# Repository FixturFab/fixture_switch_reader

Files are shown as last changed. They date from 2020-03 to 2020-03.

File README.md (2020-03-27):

# Fixture Switch Reader 

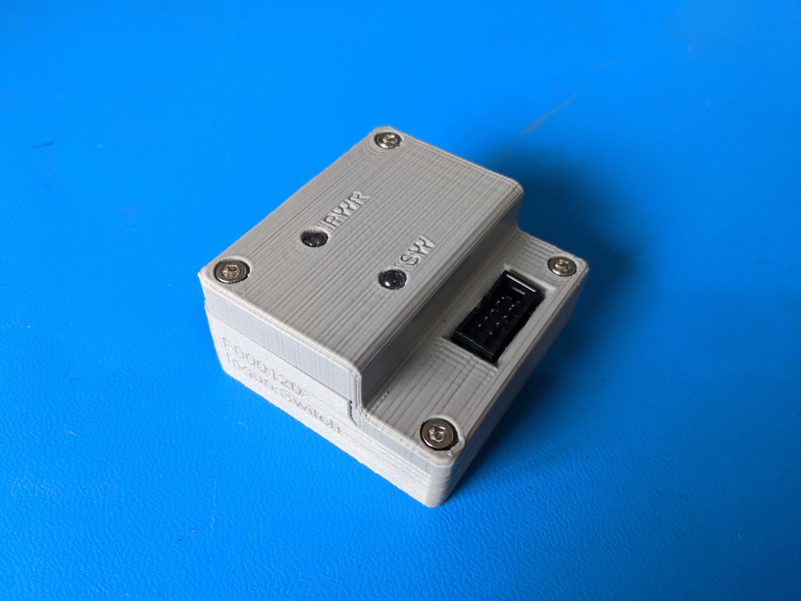
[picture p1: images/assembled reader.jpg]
Fixture Switch Reader


Project files for a USB Fixture Switch Reader using a SparkFun Pro Micro and a
Ingun FB-ABF-V-I-MA2xxx Inductive Switch. 

The Ingun FB-ABF-V-I-MA2xxx Inductive Switch is an inductive sensor which is
used to detect when a MA2xxx series manual test fixture is closed. 

FixturFab uses these switches to determine when a fixtures has been closed and
then automatically start a test run. The switch is powered by 12V, and also has 
a output of 12V when the fixture is closed. 

To interface this to a test system, an SparkFun Pro Micro is used to read the 
output of the sensor, and then relay that information to the test system over a
USB serial port. 

## Project Structure

The project is split into three main folders: 

- firmware
    - Arduino project and sketch for the SparkFun Pro Micro 
- hardware
    - Kicad schematic of the prototyped circuit 
    - Images of the perf board layout 
    - CAD files for the 3D printed enclosure 
- software 
    - Python module for communicating with the device
    
## Firmware 

Arduino 1.8.12 was used to build and program the sketch. 

The sketch reads the state of the switch input, sets the status LED, and then 
processes any available serial commands. The following serial commands are 
supported: 

- version 
    - Return device information and firmware version 
- read_switch
    - Return the current switch state 
    - 0: Fixture Open 
    - 1: Fixture Closed
    
The serial port is setup to use a BAUD rate of 115200. 
    
## Hardware 

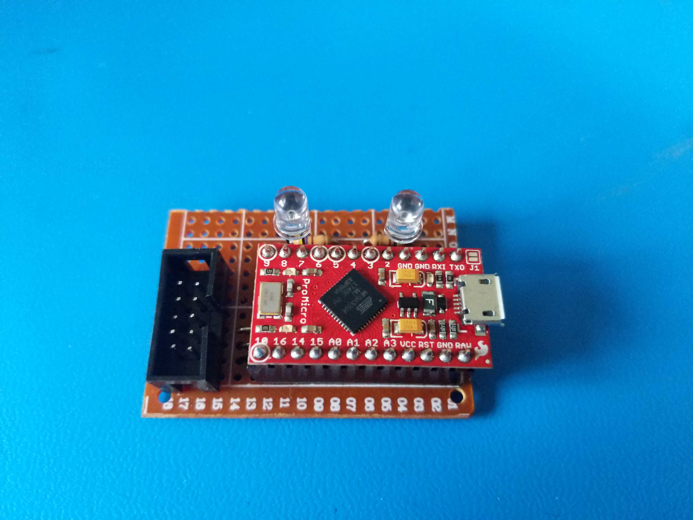
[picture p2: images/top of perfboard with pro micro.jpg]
Perfboard Prototype


A SparkFun Pro Micro was used to control this project. To build the circuit, 
perfboard and through-hole components were used. 

A Kicad schematic is available for the circuit layout. There are also pictures 
of the top and bottom of the perfboard. 

### Circuit Design and Layout 

We had a SparkFun Pro Micro (3.3V) available for this project. This device has
ATmega32u4 processor which is capable of USB communication, allowing for a USB 
serial port to be easily created. 

To interface the 12V output of the Inductive switch, a voltage divider is used. 

2 LEDs are also on the board, one connected to VCC of the processor, and the 
other is a status LED that is controlled by the processor. 

A Kicad schematic is included and shows how the circuit was prototyped, along 
with several images of the perf board layout. 

### Enclosure Design 

Fusion360 was used to design the enclosure. The enclosure consists of 2 pieces
that sandwich the protoyped device. The enclosure is held together using 
M3 heat-set inserts and fasteners. 

The STL and STEP files for the enclosure are included along with the Fusion360 
design file.  

## Software

Python 3+ is required for the provided software module. To get started, install
the required dependencies: 

```bash 
cd software/fixture_io
pip install -r requirements.text
```

To create a `FixtureSwitch` class, simple provide the serial port that the
device shows up as, for example: 

- Windows: "COM1"
- MAC: "cu.usbmodem146101"
- Linux: "/dev/ttyACM0"

```python
from fixture_io import FixtureSwitch
fixture_switch = FixtureSwitch("/dev/ttyACM0")

print(fixture_switch.get_info())
print(fixture_switch.read_switch())
```

The following API commands are available: 

- get_info()
    - Get the company, device, and firmware version from the device
- read_switch()
    - Read the switch state 
    - 0: Fixture Open 
    - 1: Fixture Closed

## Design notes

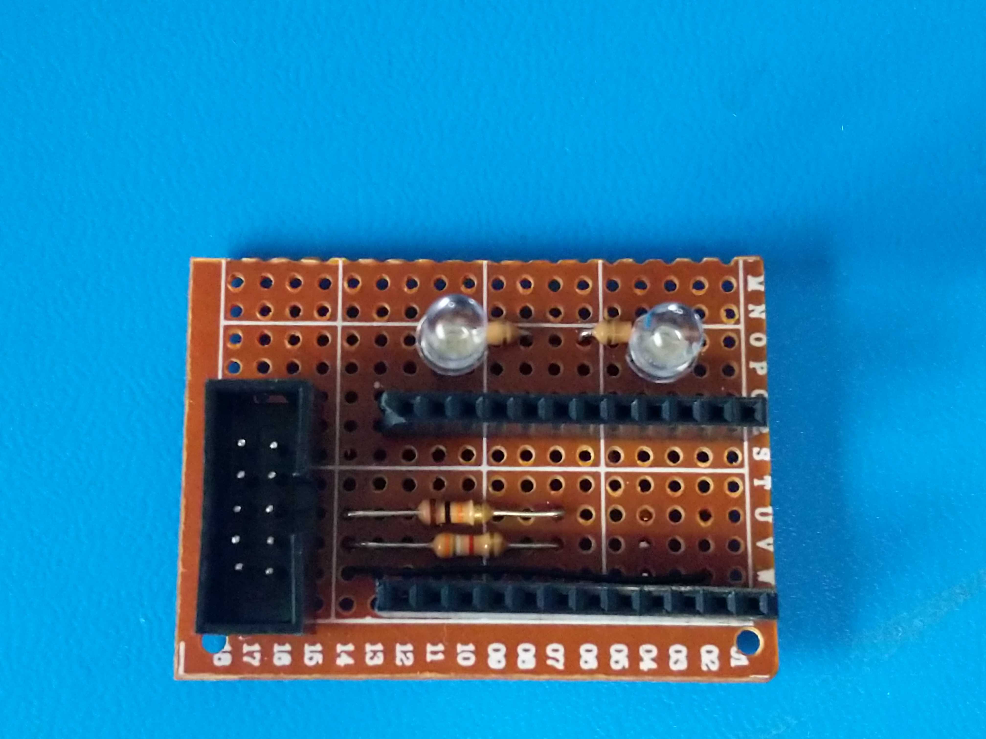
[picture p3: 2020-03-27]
hardware/fixture_switch_reader/top of perfboard.jpg

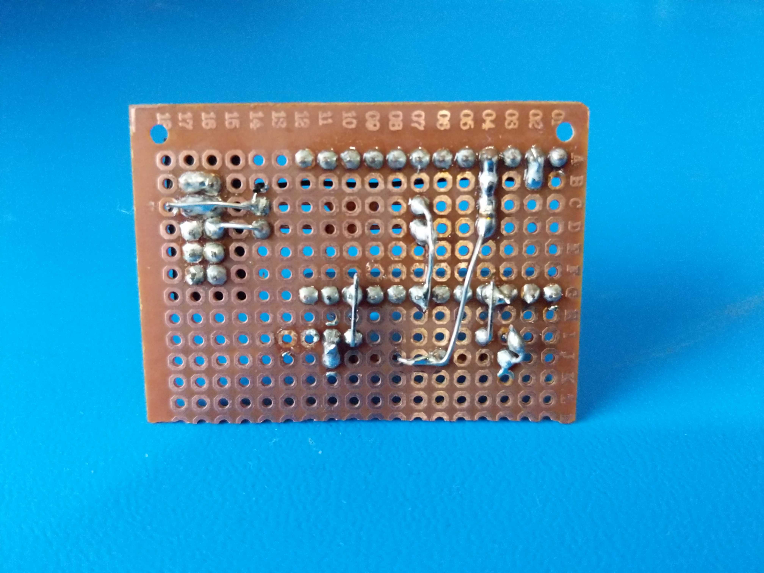
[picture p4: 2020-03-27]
hardware/fixture_switch_reader/back of perfboard.jpg

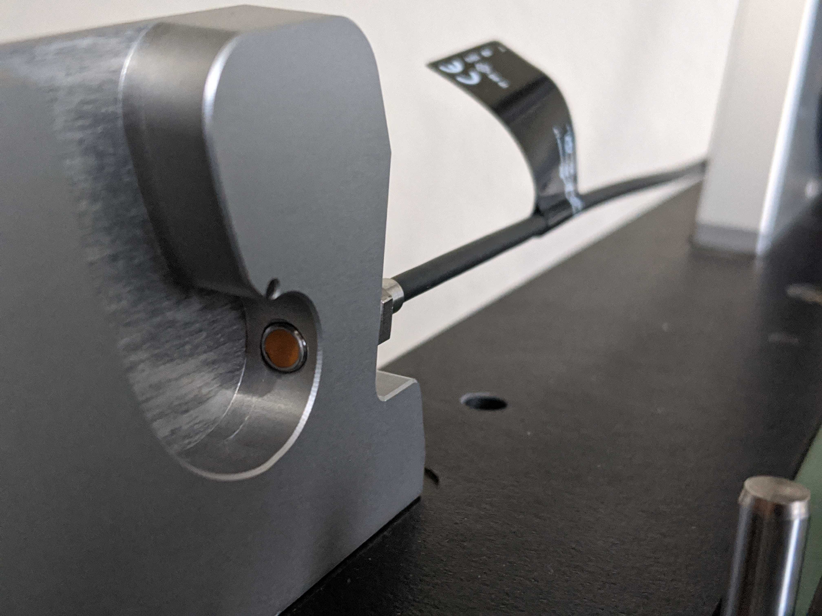
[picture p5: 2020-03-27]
images/ingun inductive sensor.jpg

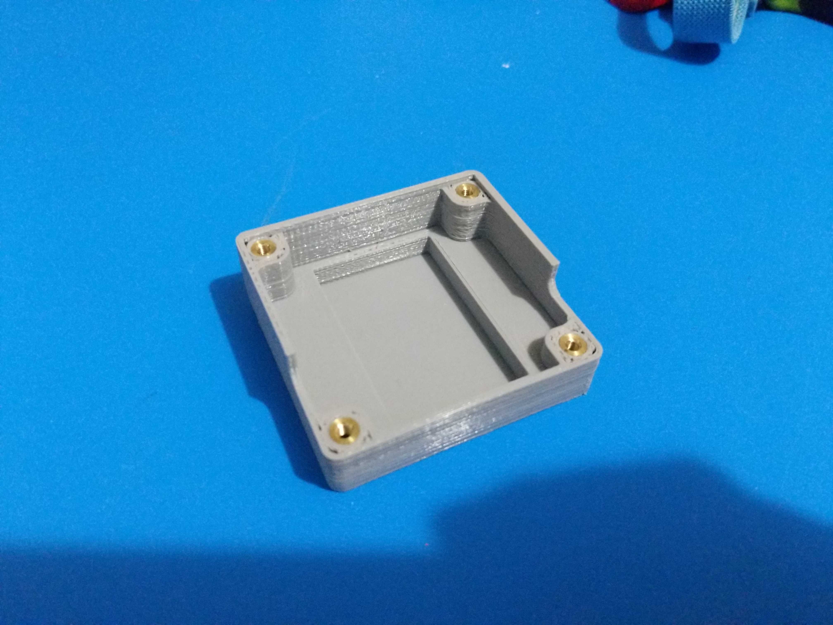
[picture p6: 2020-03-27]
images/bottom case with inserts.jpg

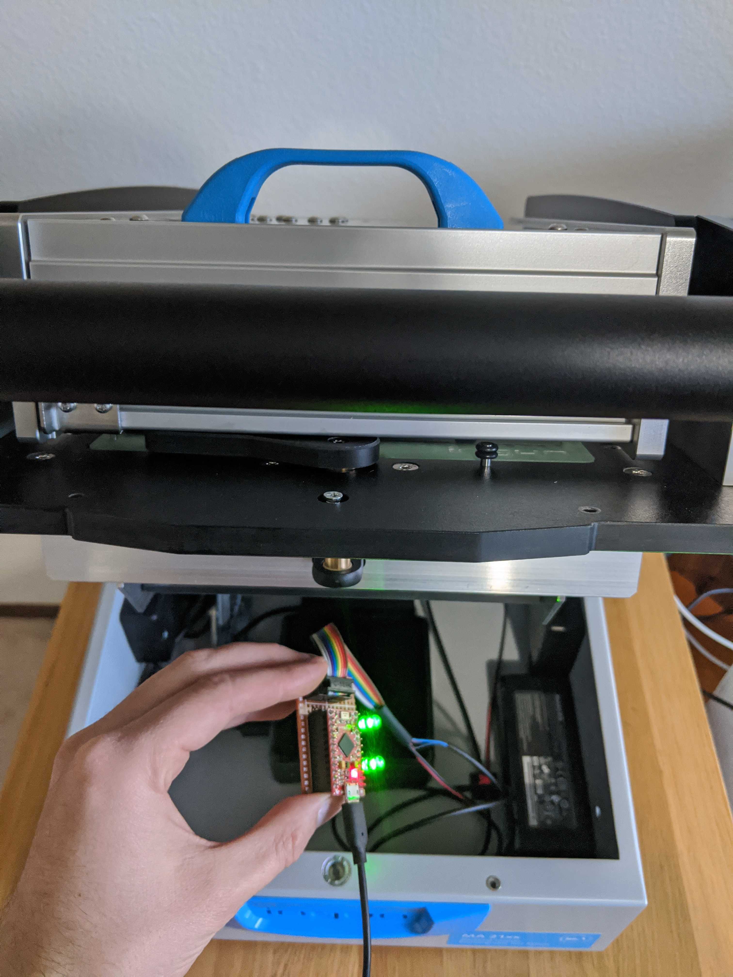
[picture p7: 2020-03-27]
images/fixture closed.jpg

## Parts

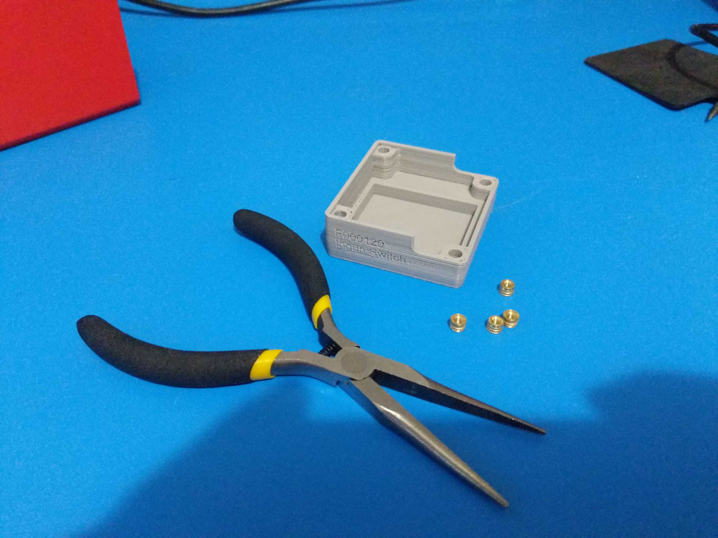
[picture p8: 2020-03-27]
images/bottom case insert parts.jpg

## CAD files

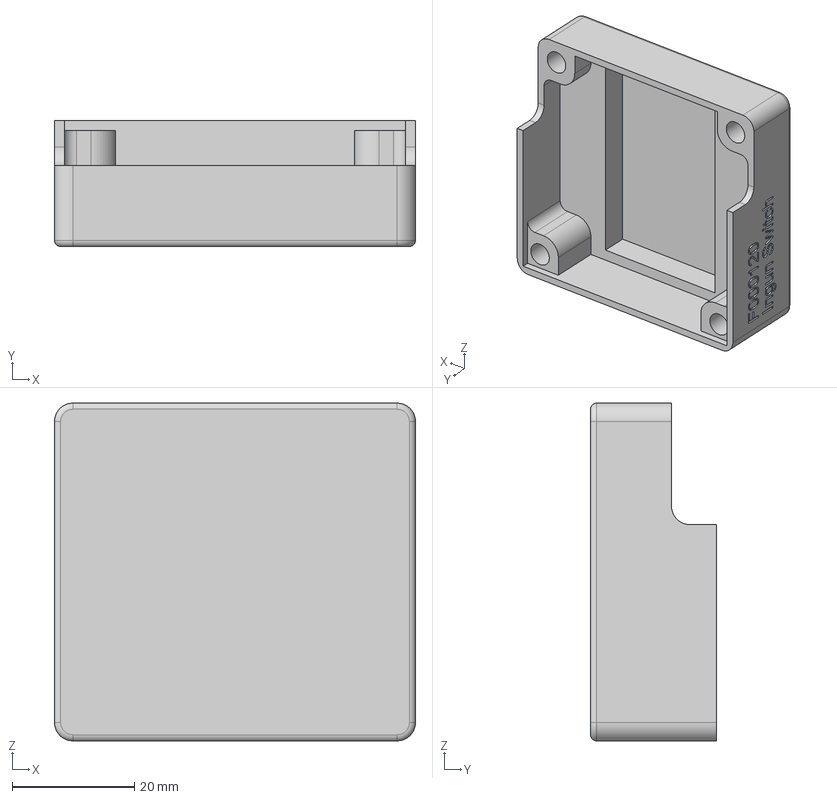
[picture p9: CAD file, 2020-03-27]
hardware/enclosure/F000118 - Case Bottom v25.step
59.0 x 20.6 x 55.2 mm

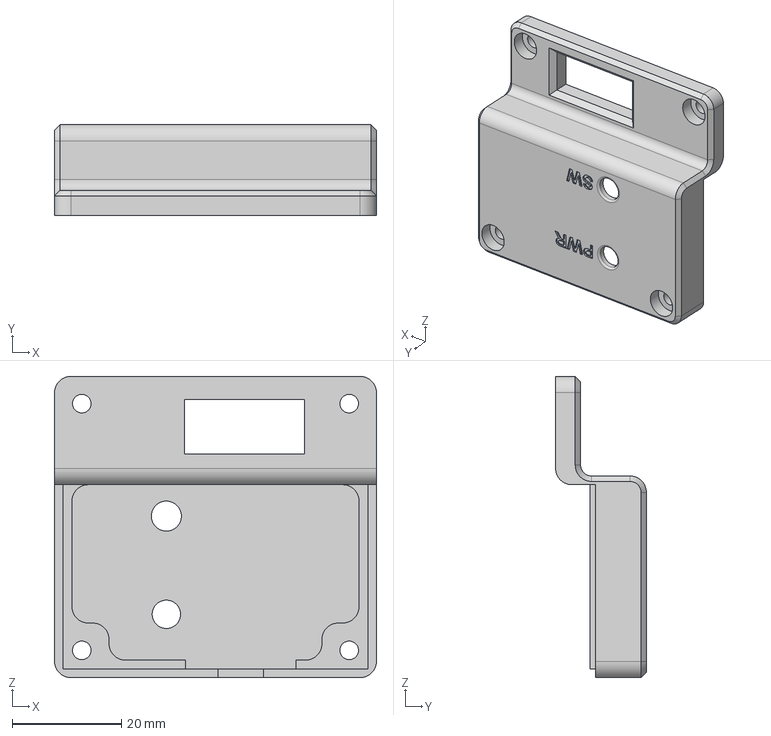
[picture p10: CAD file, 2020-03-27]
hardware/enclosure/F000119 - Case Top v43.step
59.0 x 16.6 x 55.2 mm

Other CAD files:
hardware/enclosure/F000118 - Case Bottom v25.stl
hardware/enclosure/F000119 - Case Top v43.stl
hardware/enclosure/F000120 - Protoype Ingun Switch Case Assembly v8.f3z

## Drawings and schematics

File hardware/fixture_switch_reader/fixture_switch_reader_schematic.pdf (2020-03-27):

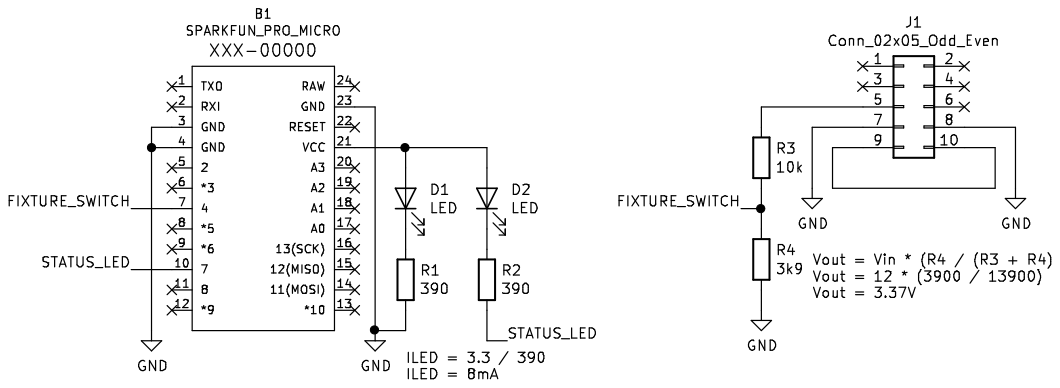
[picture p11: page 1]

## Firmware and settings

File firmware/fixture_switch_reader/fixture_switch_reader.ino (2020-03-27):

// Fixture Switch Reader
// SparkFun Micro Pro (3.3V) based USB IO Reader
//
// Connect using a serial terminal at 115200 BAUD
// Fixture Firmware Version
int FW_VER = 1;
// Pin Definitions
int STATUS_LED = 7;
int INGUN_PIN = 4;
// Global Variables
int sw_close = 0;
char buffer[256];
String command;
void setup()
{
  // Set switch pin as an input
  pinMode(INGUN_PIN, INPUT);
  // Set LED as an output
  pinMode(STATUS_LED, OUTPUT);
  // Open a USB serial port 
  Serial.begin(115200);
}
void loop() {
  // Read switch state and set the status LED
  sw_close = digitalRead(INGUN_PIN);
  digitalWrite(STATUS_LED, !sw_close);
  // Read and process available serial commands
  if(Serial.available()) {
    command = Serial.readStringUntil('\n');
    if(command.equals("read_switch")) {
      Serial.println(sw_close);
    }
    else if(command.equals("version")) {
      sprintf(buffer, "FixturFab Inc.\nFixture Switch Reader\nFW version: %d", FW_VER);
      Serial.println(buffer);
    }
    else {
      Serial.println("invalid command");
    }
  }
}

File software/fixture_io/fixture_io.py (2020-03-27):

"""
fixture_io.py

Contains FixtureSwitch class for reading fixture switch states from the
Fixture Switch Reader.
"""

import serial


class FixtureSwitch(object):
    def __init__(self, com_port):
        """
        Connect to the FixtureSwitch device using the provided COM port

        :param com_port: COM Port for the Fixture Switch
        :type com_port: str
        """
        self.ser = serial.Serial(com_port, 115200)

    def get_info(self):
        """
        Read information about the connected device

        Return a dictionary containing the following information from the
        device:

        - Company
        - Device
        - Firmware Version

        :return: Device info dictionary
        :rtype: dict
        """
        self.ser.write(b"version")
        company = self.ser.readline().strip().decode("utf-8")
        device = self.ser.readline().strip().decode("utf-8")
        fw_ver = self.ser.readline().strip().decode("utf-8")

        return {
            'company': company,
            'device': device,
            'fw_ver': int(fw_ver.split(":")[-1])
        }

    def read_switch(self):
        """
        Read the current state of the fixture switch

        :return: Fixture state, True if closed, False if open
        :rtype: bool
        """
        self.ser.write(b"read_switch")
        return bool(int(self.ser.readline().strip().decode("utf-8")))

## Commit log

2020-03-27 Inital commit of fixture switch project
    [fixture_switch_reader.kicad_pcb, fixture_switch_reader.sch]
2020-03-27 Add images Add MCAD Add Readme
    [F000118 - Case Bottom v25.step, F000118 - Case Bottom v25.stl, F000119 - Case Top v43.step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]
